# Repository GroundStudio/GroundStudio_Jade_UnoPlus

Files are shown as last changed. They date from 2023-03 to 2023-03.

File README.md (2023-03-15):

GroundStudio
====================================

Get it from [ardushop.ro](https://ardushop.ro/ro/)

Explore all the GroundStudio products at [GroundStudio.ro](https://groundstudio.ro/)

Description
-------------------
Short description of the board.

Contents
-------------------

* [/Documentation](https://github.com/GroundStudio/GroundStudio_Jade_UnoPlus/tree/main/Documentation) -- Contains documentation written during creation of this repository, with readme.md index of its own!
* [/Firmware](https://github.com/GroundStudio/GroundStudio_Jade_UnoPlus/tree/main/Firmware) -- Firmware (bootloaders, etc)
* [/Hardware](https://github.com/GroundStudio/GroundStudio_Jade_UnoPlus/tree/main/Hardware) -- Schematics, layout.
* [/Libraries](https://github.com/GroundStudio/GroundStudio_Jade_UnoPlus/tree/main/Libraries) -- Arduino/CircuitPython libraries. 
* [/Tools](https://github.com/GroundStudio) -- Tools needed for compiling, uploading bootloader, etc.

Versions
-------------------
*(Not all tags shown)*
* [V1.0.0] Initial version

License
-------------------

This is released under the [Attribution-ShareAlike 4.0 International (CC BY-SA 4.0)](https://creativecommons.org/licenses/by-sa/4.0/) license. 
**You are welcome to use this for commercial purposes.**

Please consider contributing back to this project or others to help the open-source hardware community continue to thrive and grow!

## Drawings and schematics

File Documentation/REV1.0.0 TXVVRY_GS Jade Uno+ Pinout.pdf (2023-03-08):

# GroundStudio Jade Uno+

## ISP Port

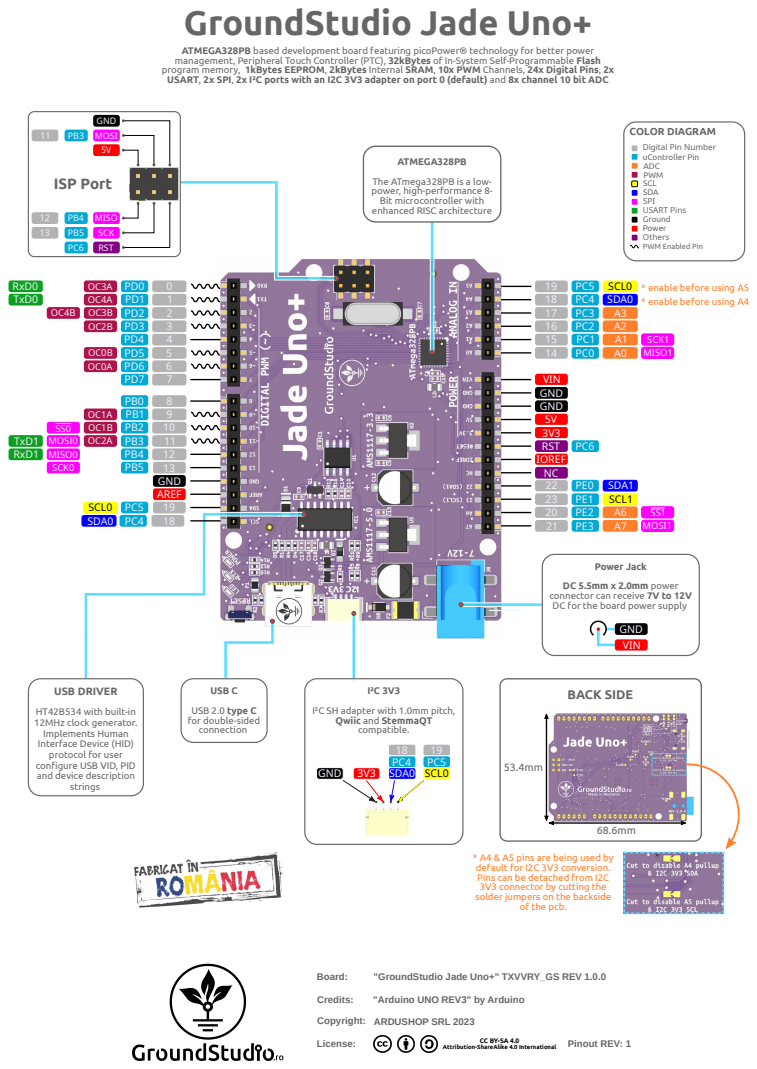
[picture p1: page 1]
Board:; Credits:; "Arduino UNO REV3" by Arduino; Copyright:; License:; ARDUSHOP SRL 2023; Pinout REV: 1; * enable before using A5; * enable before using A4; SDA0; SCL0; GND MOSI 5V; PB5 SCK; MISO; RST; MISO0; TxD0; RxD0; SCK0; AREF; GND; VIN; RST PC6; IOREF; USB DRIVER; strings; I²C 3V3; GND 3V3; SDA1 SCL1; MOSI0; TxD1 RxD1; MISO1; MOSI1; SCK1; BACK SIDE

ATMEGA328PB based development board featuring picoPower® technology for better power
management, Peripheral Touch Controller (PTC), 32kBytes of In-System Self-Programmable Flash
program memory, 1kBytes EEPROM, 2kBytes Internal SRAM, 10x PWM Channels, 24x Digital Pins, 2x
USART, 2x SPI, 2x I²C ports with an I2C 3V3 adapter on port 0 (default) and 8x channel 10 bit ADC

COLOR DIAGRAM
Digital Pin Number
uController Pin
ADC
PWM
SCL
SDA
SPI
USART Pins
Ground
Power
Others
PWM Enabled Pin

ATMEGA328PB
The ATmega328PB is a low-
power, high-performance 8-
Bit microcontroller with
enhanced RISC architecture

Power Jack
DC 5.5mm x 2.0mm power
connector can receive 7V to 12V
DC for the board power supply

USB C
USB 2.0 type C
for double-sided
connection

HT42B534 with built-in
12MHz clock generator.
Implements Human
Interface Device (HID)
protocol for user
configure USB VID, PID
and device description

I²C SH adapter with 1.0mm pitch,
Qwiic and StemmaQT
compatible.
SDA0 SCL0

* A4 & A5 pins are being used by
default for I2C 3V3 conversion.
Pins can be detached from I2C
3V3 connector by cutting the
solder jumpers on the backside

of the pcb.

"GroundStudio Jade Uno+" TXVVRY_GS REV 1.0.0

Attribution-ShareAlike 4.0 International

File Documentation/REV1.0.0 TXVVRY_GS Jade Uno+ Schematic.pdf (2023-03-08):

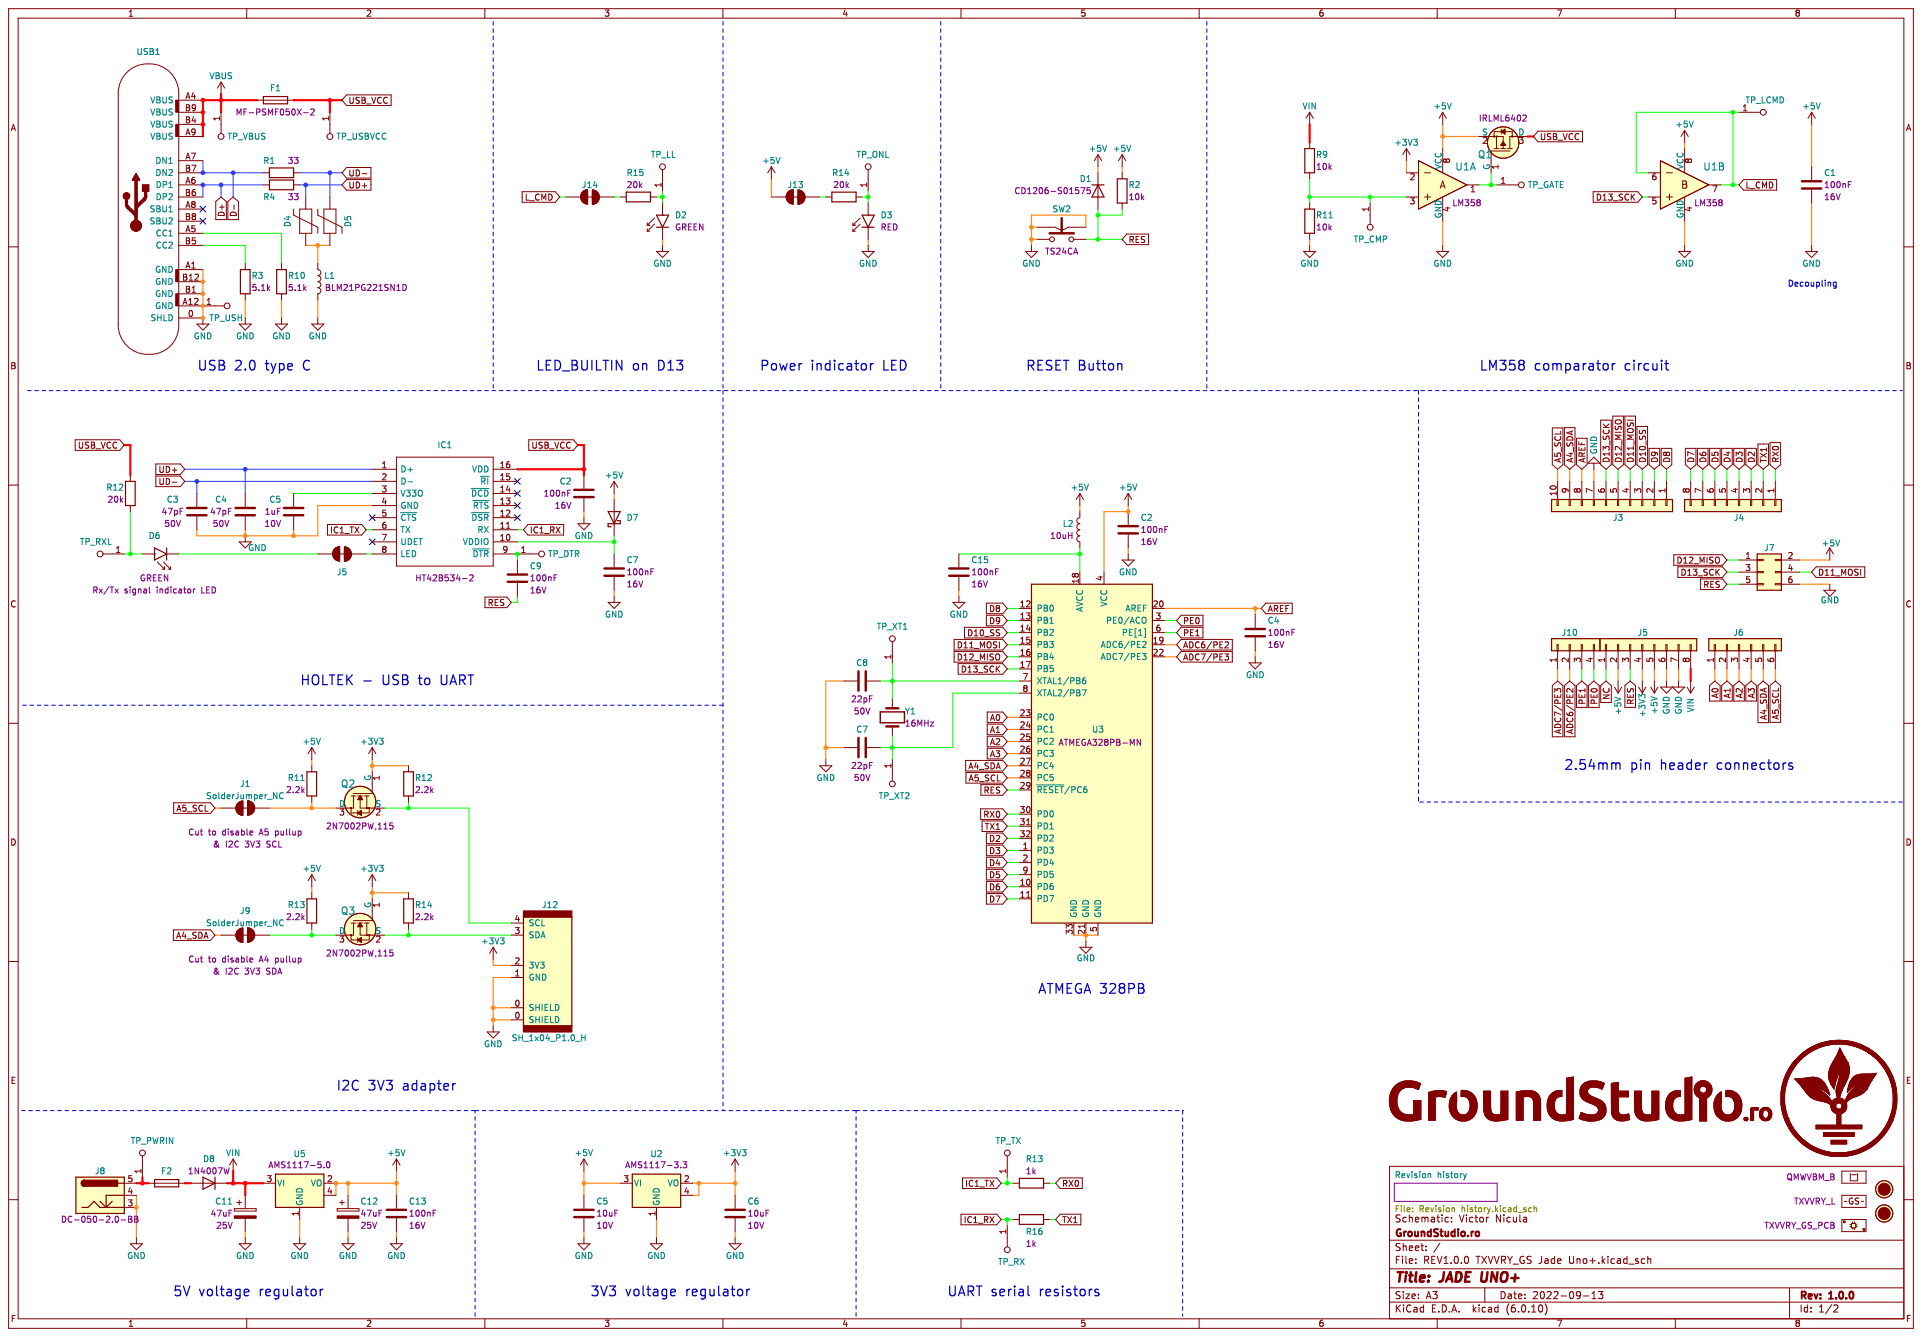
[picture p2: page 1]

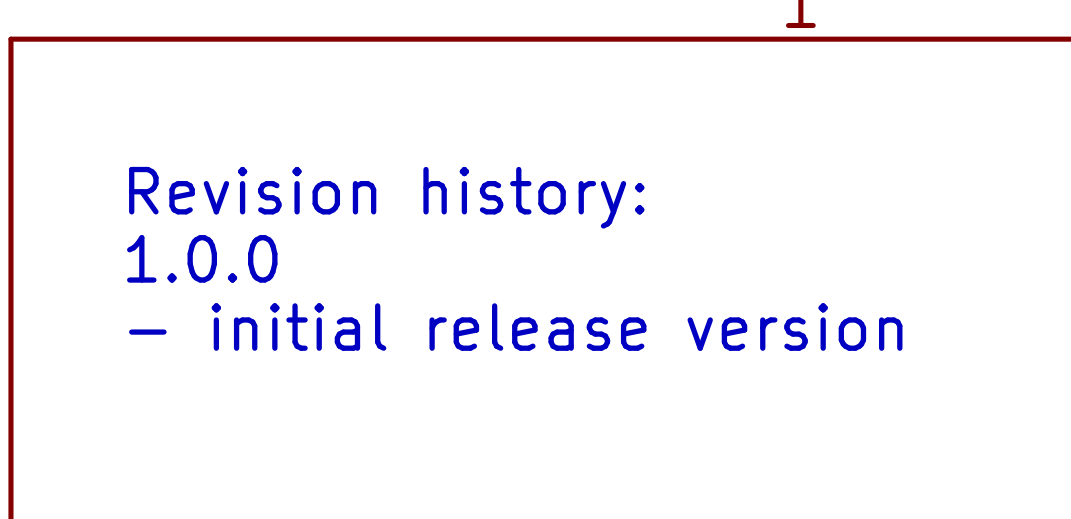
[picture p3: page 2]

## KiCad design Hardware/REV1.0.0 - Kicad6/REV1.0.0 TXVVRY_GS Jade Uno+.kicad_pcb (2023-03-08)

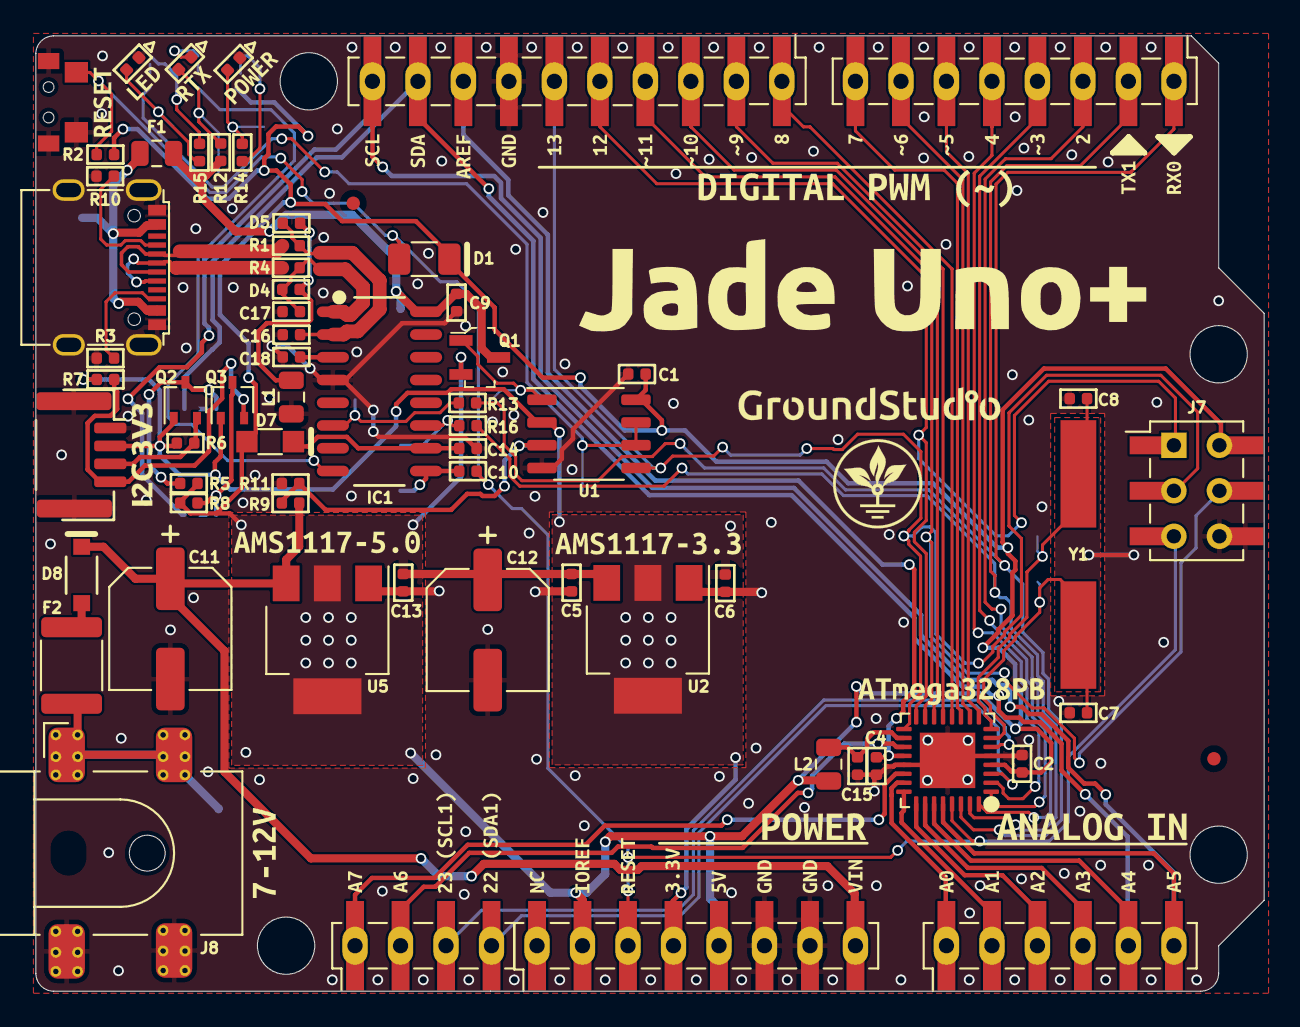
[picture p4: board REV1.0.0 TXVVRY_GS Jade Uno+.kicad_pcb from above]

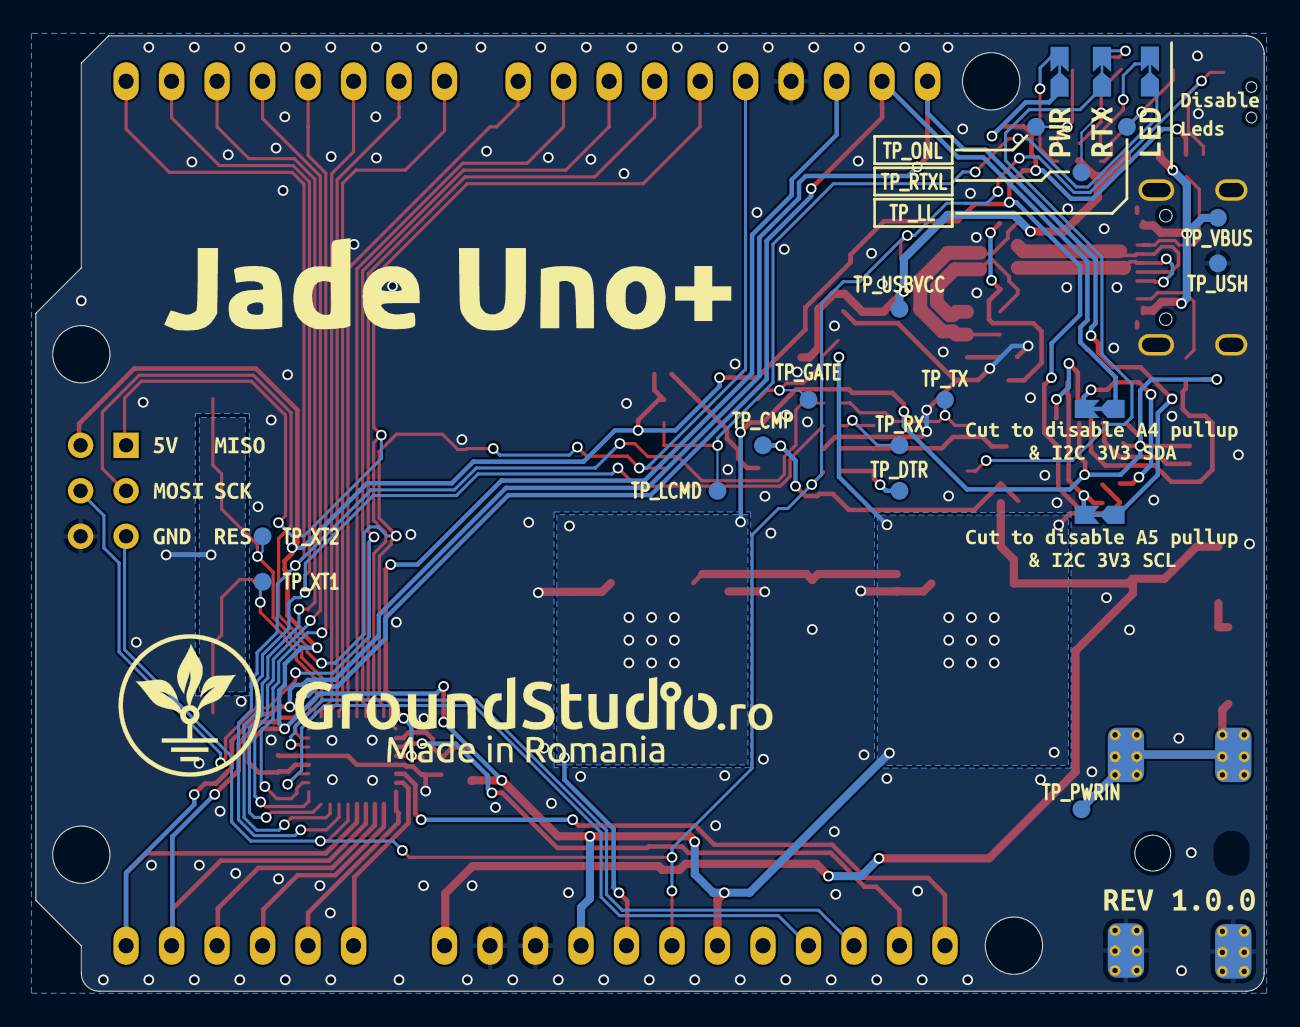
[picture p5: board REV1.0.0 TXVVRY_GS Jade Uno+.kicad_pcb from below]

Board: 2 copper layers, 68.6 x 53.3 mm, 148 parts (20 on the bottom side), 63 nets.

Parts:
C1, C2, C4, C9, C10, C13, C14, C15: C_0402_100nF_16V; C_0402
C5, C6: C_0402_10uF_10V; C_0402
C7, C8: C_0402_22pF_50V; C_0402
C11, C12: CP_Elec_6.3x5.4_47uF_25V; CP_Elec_6.3x5.4
C16, C17: C_0402_47pF_50V; C_0402
C18: C_0402_1uF_10V; C_0402
D1: D_1206_CD1206-S01575; D_1206
D2, D6: LED_0402_GREEN; LED_0402
D3: LED_0402_RED; LED_0402
D4, D5: R_0402_PS0402V014AT; R_0402
D7: SOD-323 SD103AWS; SOD-323
D8: SOD-123 1N4007W; SOD-123
F1: Fuse_0805_MF-PSMF050X-2; R_0805
F2: Fuse_1812_MF-MSMF050-2; Fuse_1812
FID1, FID2: Fiducial; Fiducial_0.75mm_Mask1.5mm
IC1: SOP-16_150MIL HT42B534-2; SOP-16_150MIL
J1, J9: SolderJumper_NC; SolderJumper_NC_0.65-A_1Oz_OuterLayer_5C-T
J2: SH_1x04_P1.0_H; SH__1x04_P1.00mm_Horizontal
J3: PinH_1x10_P2.54_V_F_SMD; PinHeader_1x10_P2.54_V_F_SMD+THT
J4, J5: PinH_1x8_P2.54_V_F_SMD; PinHeader_1x8_P2.54_V_F_SMD+THT
J6: PinH_1x6_P2.54_V_F_SMD; PinHeader_1x6_P2.54_V_F_SMD+THT
J7: PinHeader_2x03_P2.54_V_M; PinSocket_2x03_P2.54_V_F_SMD+THT
J8: DC-005-5.5-Barr_Jck_SMD; DC-005-5.5-2.0MM-SMD
J10: Conn_01x04; PinHeader_1x04_P2.54_V_F_SMD+THT
J12, J13, J14: SolderJumper_NC
L1: L_0805_BLM21PG221SN1D; L_0805
L2: L_0805_SCMI201209X100KT; L_0805
Q1: SOT-23 IRLML6402; SOT-23-3
Q2, Q3: SOT-323 2N7002PW; SOT-323_SC-70
R1, R4: R_0402_33; R_0402
R2, R9, R11: R_0402_10k; R_0402
R3, R10: R_0402_5.1k; R_0402
R5, R6, R7, R8: R_0402_2.2k; R_0402
R12, R14, R15: R_0402_20k; R_0402
R13, R16: R_0402_1k; R_0402
SW2: TS24CA
TP1: TP_VBUS; TestPoint
TP2: TP_USBVCC; TestPoint
TP3: TP_LCMD; TestPoint
TP4: TP_USH; TestPoint
TP5: TP_GATE; TestPoint
TP6: TP_CMP; TestPoint
TP7: TP_TX; TestPoint
TP8: TP_LL; TestPoint
TP9: TP_RX; TestPoint
TP10: TP_ONL; TestPoint
TP13: TP_RTXL; TestPoint
TP16: TP_XT1; TestPoint
TP18: TP_XT2; TestPoint
TP19: TP_DTR; TestPoint
TP23: TP_PWRIN; TestPoint
U1: SOP-8_3.9x4.9_P1.27 LM358; SOP-8_3.9x4.9mm_P1.27mm
U2: SOT-223 AMS1117-3.3; SOT-223
U3: ATmega328PB-MUR; QFN-32-1EP_5x5_P0.5_EP3.1x3.1
U5: SOT-223 AMS1117-5.0; SOT-223
USB1: USB_C_FULL; USB_C_C167321
Y1: HC49-SMD 5M0-1600A2020; Crystal_HC49-SMD
kibuzzard-6304B8AA: G***; kibuzzard-6304B8AA
kibuzzard-6304B8C4: G***; kibuzzard-6304B8C4
kibuzzard-6304B90F: G***; kibuzzard-6304B90F
kibuzzard-6304B959: G***; kibuzzard-6304B959
kibuzzard-6304BA0A: G***; kibuzzard-6304BA0A
kibuzzard-6304BA95: G***; kibuzzard-6304BA95
kibuzzard-6304BB5A: G***; kibuzzard-6304BB5A
kibuzzard-6304BB7B: G***; kibuzzard-6304BB7B
kibuzzard-6304BB25: G***; kibuzzard-6304BB25
kibuzzard-6304BB68: G***; kibuzzard-6304BB68
kibuzzard-6304BC48: G***; kibuzzard-6304BC48
kibuzzard-6304BC55: G***; kibuzzard-6304BC55
kibuzzard-6304BC77: G***; kibuzzard-6304BC77
kibuzzard-6304BD32: G***; kibuzzard-6304BD32
kibuzzard-6304BD56: G***; kibuzzard-6304BD56
kibuzzard-6304BD88: G***; kibuzzard-6304BD88
kibuzzard-6304BDD1: G***; kibuzzard-6304BDD1
kibuzzard-6304BDFC: G***; kibuzzard-6304BDFC
kibuzzard-6304BE0A: G***; kibuzzard-6304BE0A
kibuzzard-6304BE24, kibuzzard-6304BE24#2, kibuzzard-6304BE24#3: G***; kibuzzard-6304BE24
kibuzzard-6304BE44: G***; kibuzzard-6304BE44
kibuzzard-6304BE81: G***; kibuzzard-6304BE81
kibuzzard-6304BEA3: G***; kibuzzard-6304BEA3
kibuzzard-6304BEBA: G***; kibuzzard-6304BEBA
kibuzzard-6304BEF7: G***; kibuzzard-6304BEF7
kibuzzard-6304BF4E: G***; kibuzzard-6304BF4E
kibuzzard-6304BF08: G***; kibuzzard-6304BF08
kibuzzard-6304BF17: G***; kibuzzard-6304BF17
kibuzzard-6304BF64: G***; kibuzzard-6304BF64
kibuzzard-6304BF84: G***; kibuzzard-6304BF84
kibuzzard-6304BFA8: G***; kibuzzard-6304BFA8
kibuzzard-6304BFB9: G***; kibuzzard-6304BFB9
kibuzzard-6304BFCD: G***; kibuzzard-6304BFCD
kibuzzard-6304BFE9: G***; kibuzzard-6304BFE9
kibuzzard-6304BFFA: G***; kibuzzard-6304BFFA
kibuzzard-6304C1E0: G***; kibuzzard-6304C1E0
kibuzzard-6304C1FC: G***; kibuzzard-6304C1FC
kibuzzard-6304C4A6: G***; kibuzzard-6304C4A6
kibuzzard-6304C4B7: G***; kibuzzard-6304C4B7
kibuzzard-6304C4F3: G***; kibuzzard-6304C4F3
kibuzzard-6304C05A: G***; kibuzzard-6304C05A
kibuzzard-6304C6B6: G***; kibuzzard-6304C6B6
kibuzzard-6304C016: G***; kibuzzard-6304C016
kibuzzard-6304C31B: G***; kibuzzard-6304C31B
kibuzzard-6304C044: G***; kibuzzard-6304C044
kibuzzard-6304C46A: G***; kibuzzard-6304C46A
kibuzzard-6304C47B: G***; kibuzzard-6304C47B
kibuzzard-6304C185: G***; kibuzzard-6304C185
kibuzzard-6304C295: G***; kibuzzard-6304C295
kibuzzard-6304C450: G***; kibuzzard-6304C450
kibuzzard-6304C490: G***; kibuzzard-6304C490
kibuzzard-6304C525: G***; kibuzzard-6304C525
kibuzzard-6304C555: G***; kibuzzard-6304C555
kibuzzard-6304C570: G***; kibuzzard-6304C570
kibuzzard-6304D41D: G***; kibuzzard-6304D41D
kibuzzard-6304D43B: G***; kibuzzard-6304D43B
kibuzzard-6304D472: G***; kibuzzard-6304D472
kibuzzard-632175D7: G***; kibuzzard-632175D7
kibuzzard-63208071: G***; kibuzzard-63208071
kibuzzard-63217612: G***; kibuzzard-63217612

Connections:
+3V3: C6.1, J2.2 (3V3), J5.4, Q2.1 (G), Q3.1 (G), R6.1, R7.1, U1.2, U2.2 (VO), U2.4
+5V: C1.1, C2.1, C5.1, C12.1, C13.1, D1.1 (K), D7.2 (A), J5.2, J5.5, J7.2, J13.1, L2.1, Q1.2 (S), R2.2, R5.2, R8.2, U1.8 (VCC), U2.3 (VI), U3.4 (VCC), U5.2 (VO), U5.4
A0: J6.1, U3.23 (PC0)
A1: J6.2, U3.24 (PC1)
A2: J6.3, U3.25 (PC2)
A3: J6.4, U3.26 (PC3)
A4_SDA: J3.9, J6.5, J9.1, U3.27 (PC4)
A5_SCL: J1.1, J3.10, J6.6, U3.28 (PC5)
ADC6/PE2: J10.2, U3.19 (ADC6/PE2)
ADC7/PE3: J10.1, U3.22 (ADC7/PE3)
AREF: C4.1, J3.8, U3.20 (AREF)
D2: J4.3, U3.32 (PD2)
D3: J4.4, U3.1 (PD3)
D4: J4.5, U3.2 (PD4)
D5: J4.6, U3.9 (PD5)
D6: J4.7, U3.10 (PD6)
D7: J4.8, U3.11 (PD7)
D8: J3.1, U3.12 (PB0)
D9: J3.2, U3.13 (PB1)
D10_SS: J3.3, U3.14 (PB2)
D11_MOSI: J3.4, J7.4, U3.15 (PB3)
D12_MISO: J3.5, J7.1, U3.16 (PB4)
D13_SCK: J3.6, J7.3, U1.5, U3.17 (PB5)
D+: R4.1, USB1.A6 (DP1), USB1.B6 (DP2)
D-: R1.1, USB1.A7 (DN1), USB1.B7 (DN2)
GND: C1.2, C2.2, C4.2, C5.2, C6.2, C7.1, C8.1, C9.2, C11.2, C12.2, C13.2, C14.2, C15.2, C16.1, C17.1, C18.2, D2.1 (K), D3.1 (K), IC1.4 (GND), J2.0 (SHIELD), J2.1 (GND), J3.7, J5.6, J5.7, J7.6, J8.3, J8.4, L1.2, R3.1, R10.2, R11.1, SW2.1, SW2.2, SW2.3, TP4.1, U1.4 (GND), U2.1 (GND), U3.5 (GND), U3.21 (GND), U3.33 (GND), U5.1 (GND), USB1.0 (SHLD), USB1.A1 (GND), USB1.A12 (GND), USB1.B1 (GND), USB1.B12 (GND)
IC1_RX: IC1.11 (RX), R16.2, TP9.1
IC1_TX: IC1.6 (TX), R13.2, TP7.1
L_CMD: J14.1, TP3.1, U1.6, U1.7
unnamed: C7.2, TP16.1, U3.7 (XTAL1/PB6), Y1.1
unnamed: C8.2, TP18.1, U3.8 (XTAL2/PB7), Y1.2
unnamed: C10.1, IC1.9 (~DTR), TP19.1
unnamed: C14.1, D7.1 (K), IC1.10 (VDDIO)
unnamed: C15.1, L2.2, U3.18 (AVCC)
unnamed: C18.1, IC1.3 (V33O)
unnamed: D2.2 (A), R15.2, TP8.1
unnamed: D3.2 (A), R14.2, TP10.1
unnamed: D4.1, D5.2, L1.1
unnamed: D6.1 (K), J12.2
unnamed: D6.2 (A), R12.1, TP13.1
unnamed: D8.2 (A), F2.1
unnamed: F2.2, J8.5, TP23.1
unnamed: IC1.8 (LED), J12.1
unnamed: J1.2, Q3.3 (D), R8.1
unnamed: J2.3 (SDA), Q2.2 (S), R6.2
unnamed: J2.4 (SCL), Q3.2 (S), R7.2
unnamed: J9.2, Q2.3 (D), R5.1
unnamed: J13.2, R14.1
unnamed: J14.2, R15.1
unnamed: Q1.1 (G), TP5.1, U1.1
unnamed: R3.2, USB1.B5 (CC2)
unnamed: R10.1, USB1.A5 (CC1)
unnamed: R9.1, R11.2, TP6.1, U1.3
PE0: J10.4, U3.3 (PE0/ACO)
PE1: J10.3, U3.6 (PE[1])
RES: C10.2, D1.2 (A), J5.3, J7.5, R2.1, SW2.4, U3.29 (~RESET/PC6)
RX0: J4.1, R13.1, U3.30 (PD0)
TX1: J4.2, R16.1, U3.31 (PD1)
UD+: C17.2, D4.2, IC1.1 (D+), R4.2
UD-: C16.2, D5.1, IC1.2 (D-), R1.2
USB_VCC: C9.1, F1.1, IC1.16 (VDD), Q1.3 (D), R12.2, TP2.1
VBUS: F1.2, TP1.1, USB1.A4 (VBUS), USB1.A9 (VBUS), USB1.B4 (VBUS), USB1.B9 (VBUS)
VIN: C11.1, D8.1 (K), J5.8, R9.2, U5.3 (VI)
